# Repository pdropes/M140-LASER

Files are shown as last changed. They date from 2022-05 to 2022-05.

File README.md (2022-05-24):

# 2W LASER - M140 Nichia

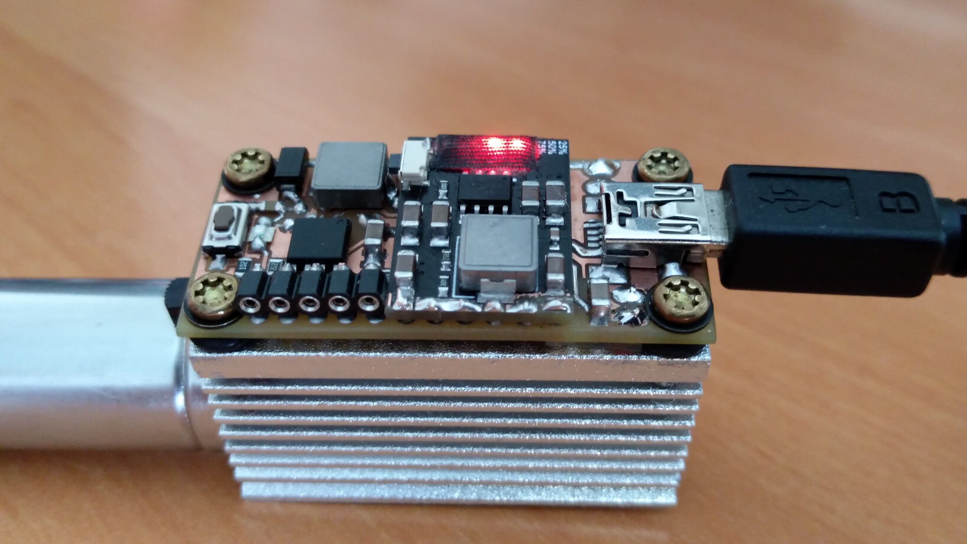
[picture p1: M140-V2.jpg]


Construction of a driver for this small diode, power by 18650 battery.
- Max output = 4.8V 2A
- 4 Selectable power levels (0.1-0.5-1.0-1.5A)
- Constant CC with soft start
- Battery monitoring in charge and discharge

Firmware: Bascom AVR 2.0.8.1; Layout: CadSoft EAGLE 6.5.0

*Stay creative (& always wear safety glasses)

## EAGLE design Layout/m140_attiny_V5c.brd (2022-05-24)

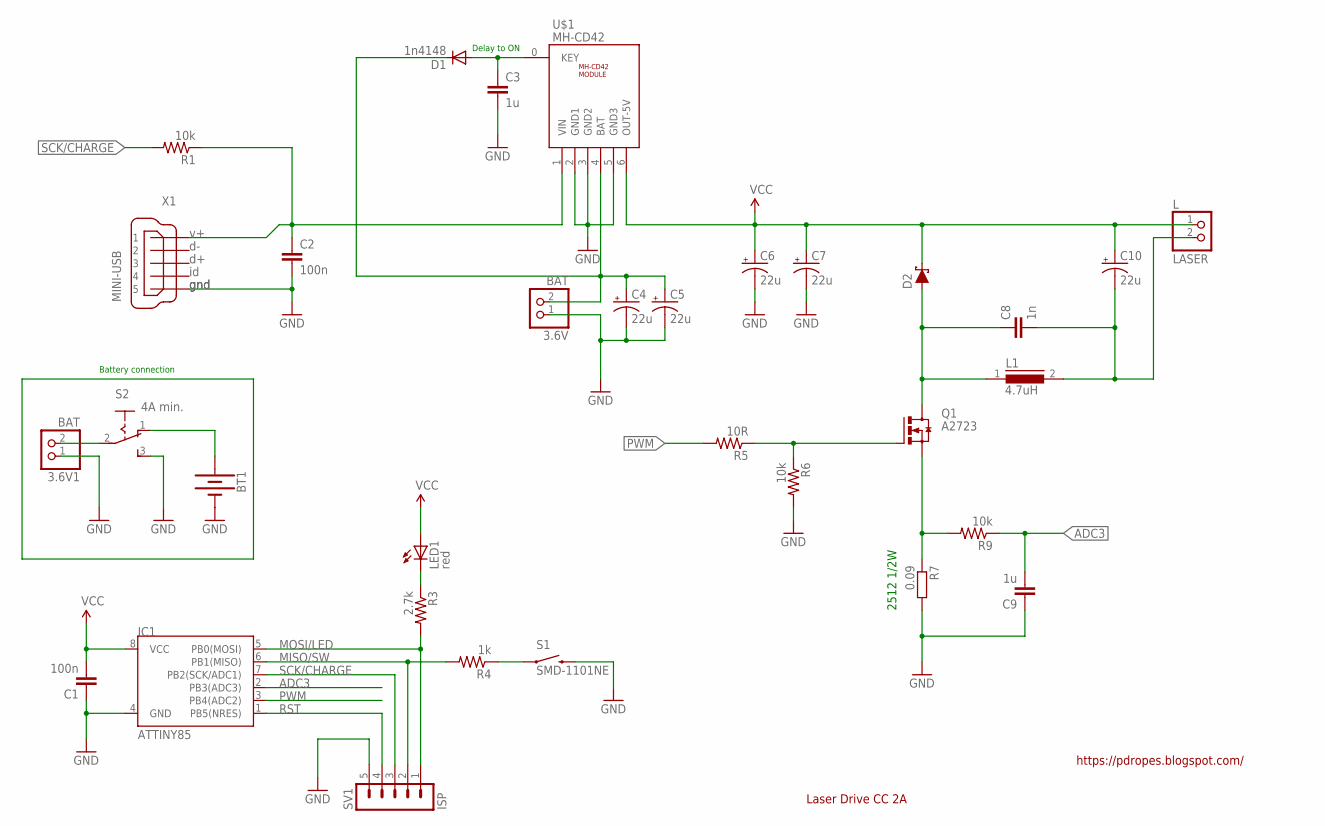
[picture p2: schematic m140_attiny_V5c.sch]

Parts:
3.6V, 3.6V1: BAT; 1X02
BT1: BATTERY-18650; BATTERY_18650-HOLDER
C1, C2: 100n; 0805
C3, C9: 1u; 0805
C4, C5, C6, C7, C10: 22u; EIA3216-KIT
C8: 1n; 0805
D1: 1n4148; MICROMELF-R
D2: 3A/40V/500mV; SMA-DIODE
IC1: ATTINY85; SO08-EIAJ
L: LASER; 1X02
L1: 4.7uH; DR74
LED1: red; CHIPLED_0805
Q1: A2723; SOP-ADVANCE
R1, R6, R9: 10k; 0805
R3: 2.7k; 0805
R4: 1k; 0805
R5: 10R; 0805
R7: 0.09; R2512
S1: SMD-1101NE; TACTILE-SWITCH-1101NE
S2: 4A min.; 255SB
SV1: ISP; MA05-1
U$1: MH-CD42
X1: MINI-USB; 32005-301

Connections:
ADC3: C9.2, IC1.2 (PB3(ADC3)), R9.1
B+: 3.6V.2, C4.A (+), C5.A (+), D1.C, U$1.4 (BAT)
GND: 3.6V.1, 3.6V1.1, BT1.GND@1 (-), C1.1, C2.2, C3.2, C4.C (-), C5.C (-), C6.C (-), C7.C (-), C9.1, IC1.4 (GND), R6.2, R7.2, S1.P$2 (2), S2.3 (S), SV1.5, U$1.2 (GND1), U$1.3 (GND2), U$1.5 (GND3), X1.5
KEY: C3.1, D1.A, U$1.0 (KEY)
L-: C8.2, C10.C (-), L.2, L1.2
MISO/SW: IC1.6 (PB1(MISO)), R4.2, SV1.2
MOSI/LED: IC1.5 (PB0(MOSI)), R3.2, SV1.1
unnamed: BT1.PWR@1 (+), S2.1 (O)
unnamed: R4.1, S1.P$1 (1)
unnamed: 3.6V1.2, S2.2
unnamed: LED1.C, R3.1
PWM: IC1.3 (PB4(ADC2)), R5.2
Q1D: C8.1, D2.A, L1.1, Q1.5 (D), Q1.6 (D), Q1.7 (D), Q1.8 (D), Q1.TH (D)
Q1G: Q1.4 (G), R5.1, R6.1
Q1S: Q1.1 (S), Q1.2 (S), Q1.3 (S), R7.1, R9.2
RST: IC1.1 (PB5(NRES)), SV1.4
SCK/CHARGE: IC1.7 (PB2(SCK/ADC1)), R1.2, SV1.3
USB+: C2.1, R1.1, U$1.1 (VIN), X1.1
VCC: C1.2, C6.A (+), C7.A (+), C10.A (+), D2.C, IC1.8 (VCC), L.1, LED1.A, U$1.6 (OUT-5V)

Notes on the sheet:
Laser Drive CC 2A
gnd
Delay to ON
2512 1/2W
Battery connection
https://pdropes.blogspot.com/

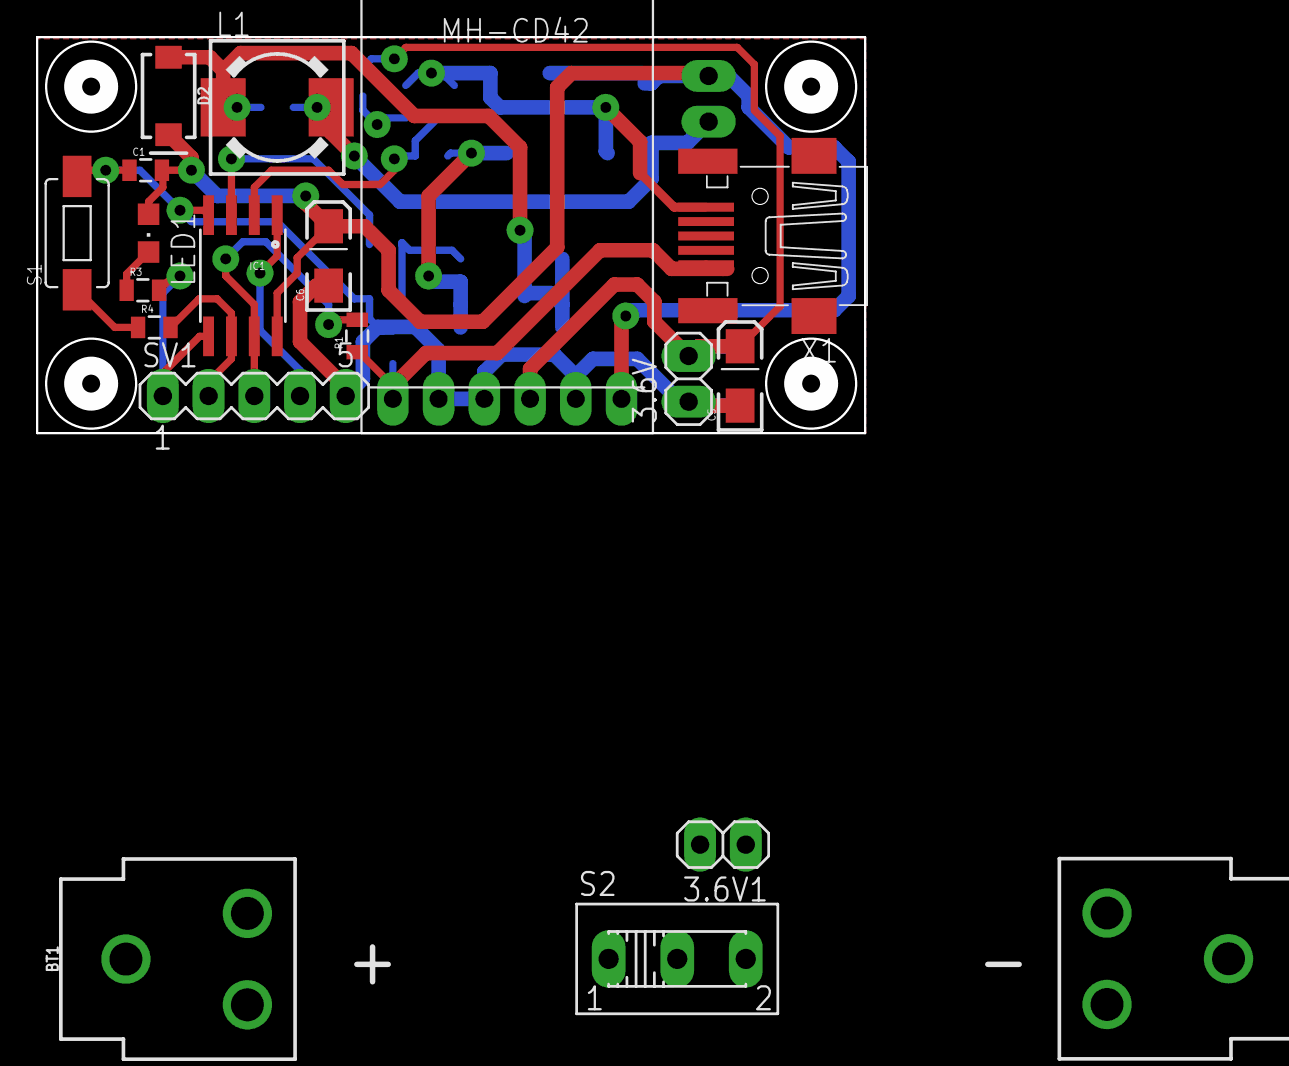
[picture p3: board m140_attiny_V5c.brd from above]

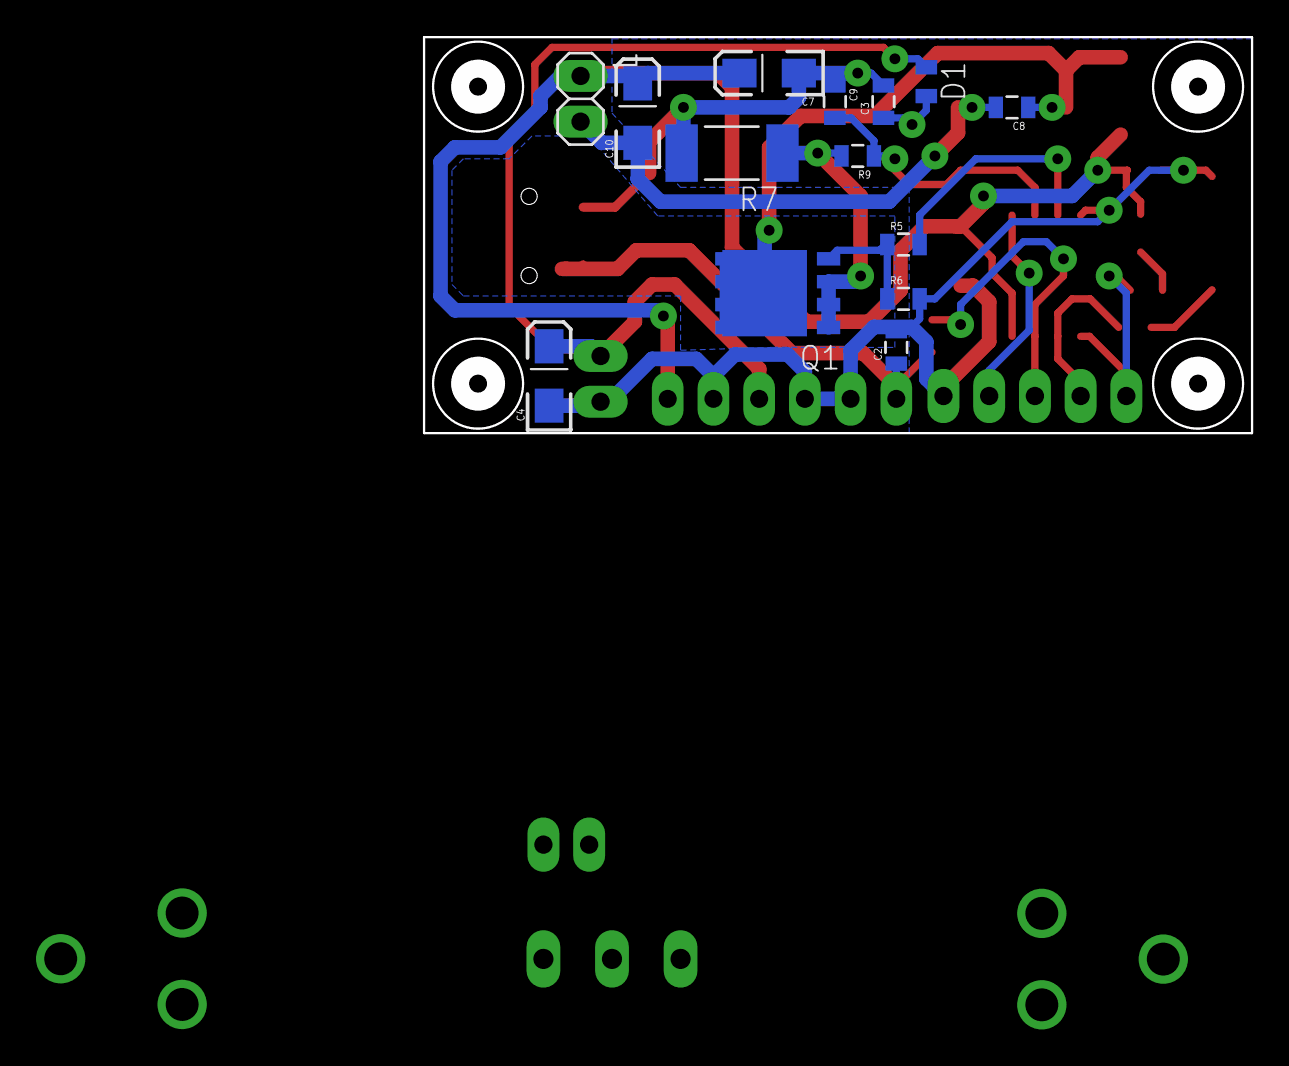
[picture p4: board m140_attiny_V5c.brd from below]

Board: 2 copper layers, 46.0 x 22.0 mm, 33 parts (14 on the bottom side), 19 nets.

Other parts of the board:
U$2: LASER_HEAT_SINK

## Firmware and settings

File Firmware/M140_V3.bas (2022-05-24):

'04-05-2022
'FUSES: E:FF H:DF L:E1

'Pinout ATtiny85:
'1- PB5 (PCINT5 / Reset / ADC0 / DW)
'2- PB3 (PCINT3/XTAL1/CLKI/OC1B/ADC3)
'3- PB4 (PCINT4/XTAL2/CLKO/_OC1B/ADC2)
'4- GND
'5- PB0 (MOSI/DI/SDA/AIN0/OC0A/_OC1A/AREF/PCINT0)
'6- PB1 (MISO/DO/AIN1/OC0B/OC1A/PCINT1)
'7- PB2 (SCK/USCK/SCL/ADC1/T0/INT0/PCINT2)
'8- VCC

'PB0 = SWITCH
'PB1 = LED
'PB2 = USB_charger
'PB3 = ADC3
'PB4 = PWM


$regfile = "attiny85.dat"
$crystal = 16000000
'$hwstack = 32
'$swstack = 10
'$framesize = 40

Dim Value As Word
Dim Ilaser As Word
Dim Cnt , Cnt2 As Word
Dim Pwm_value As Byte

Dim Pselect(4) As Byte                                      'Bascom não aceita arrays de constantes :/

'RSense =0.09ohms
'ADC Ref=1.1V
'Current=1.1V/0.09ohms =12.2(2)A
'LSb=12.2(2)/1024=0.011936V
'0.1A=0.1/ 0.011936V = ~8,4
'0.5A=0.5/ 0.011936V = ~41,9
'1.0A=1.0/ 0.011936V = ~83,8
'1.5A=1.5/ 0.011936V = ~125,7
Pselect(1) = 9 : Pselect(2) = 42 : Pselect(3) = 84 : Pselect(4) = 126       '0.1/0.5/1.0/1.5A


Dim Power_position , Power_output As Word                   'Tem de ser word Power_output

Config Adc = Single , Prescaler = 4 , Reference = Internal_1.1

Const Adc_ilaser = 3

Switch Alias Pinb.0
Led Alias Portb.1
Charger Alias Pinb.2

Config Charger = Input
Charger = 0
Config Led = Output
Led = 1
Config Switch = Input
Switch = 1

Declare Function Get_adc(byval Channel As Byte) As Word
Declare Sub Pwm(_get As Word , _wanted As Word)

'-----------------------------PLL AS CLOCK SOURCE for 16MHz-------------------------
Pllcsr.plle = 1
While Pllcsr.plock = 0
Wend
Pllcsr.pcke = 1
!Ldi R24 , 110
!Out Osccal , R24

'----------------------------TIMER 1 PWM
'TCCR1 – Timer/Counter1 Control Register
'CTC1 PWM1A COM1A1 COM1A0 CS13 CS12 CS11 CS10
Tccr1 = Bits(cs11 , Cs10 )
'GTCCR – General Timer/Counter1 Control Register
'TSM PWM1B COM1B1 COM1B0 FOC1B FOC1A PSR1 PSR0
Gtccr = Bits(pwm1b , Com1b1)
'TCNT1 – Timer/Counter1
Tcnt1 = &H00
Ocr1a = &H00
Ocr1b = &H00                                                'PWM VALUE
Ocr1c = &HFF
Config Portb.4 = Output

'Config Portb.1 = Output
'Open "comb.1:4800,8,n,1" For Output As #1

'------------------------------------------MAIN--------------------------------------------

Enable Interrupts

Power_position = 0
Power_output = Pselect(1)
Pwm_value = 0
Led = 0
Waitms 500
Led = 1

Do
    'Espera que o switch seja activado, pisca a cada segundo
    While Switch = 1

        'Verifica se o carregador está ligado
        While Charger = 1
            Led = 0
            For Cnt = 0 To 100
                If Charger = 0 Then Cnt = 100
                Waitms 5
            Next Cnt
            Led = 1
            For Cnt = 0 To 100
                If Charger = 0 Then Cnt = 100
                Waitms 5
            Next Cnt
        Wend

        For Cnt = 0 To 250
            If Switch = 0 Then Cnt = 250
            Waitms 4
        Next Cnt
        Led = 0
        Waitms 5
        Led = 1
    Wend

    'Se passado 150ms o switch continuar activado, então habilita o laser
    Waitms 150

    Led = 0
    While Switch = 0
        Ilaser = Get_adc(adc_ilaser)
        Call Pwm(ilaser , Power_output)
        Waitms 3                                            'soft start
    Wend
    Led = 1

    'Espera um possível 2º click para alterar a potência
    If Ocr1b = 0 Then
        For Cnt = 0 To 150
            Waitms 1
            If Switch = 0 Then
                Bitwait Switch , Set
                Incr Power_position
                Power_position = Power_position And &B11    '0..3
                Power_output = Pselect(power_position + 1)  'Arrays começam em 1
             'Apresenta a potência
                Waitms 500
                For Cnt2 = 0 To Power_position
                    Led = 0
                    Waitms 100
                    Led = 1
                    Waitms 200
                Next Cnt2
                Cnt = 150
            End If
        Next Cnt
    End If


    Ocr1b = 0                                               'desliga o pwm
    Pwm_value = 0
    Waitms 200
Loop

'---------------------------------------ADC-----------------------------------------------
Function Get_adc(byval Channel As Byte) As Word
    Dim Multi_sample As Byte
    Dim Adc_value As Word

    Adc_value = 0
    For Multi_sample = 0 To 49
        Adc_value = Adc_value + Getadc(channel)
    Next Multi_sample
    Adc_value = Adc_value / 50
    Get_adc = Adc_value
End Function

'-------------------------------------TUNE PWM------------------------------------------
Sub Pwm(_get As Word , _wanted As Word)
    If _get < _wanted And Pwm_value < 200 Then
        Incr Pwm_value
        Ocr1b = Pwm_value
    End If
    If _get > _wanted And Pwm_value > 0 Then
        Decr Pwm_value
        Ocr1b = Pwm_value
    End If
End Sub

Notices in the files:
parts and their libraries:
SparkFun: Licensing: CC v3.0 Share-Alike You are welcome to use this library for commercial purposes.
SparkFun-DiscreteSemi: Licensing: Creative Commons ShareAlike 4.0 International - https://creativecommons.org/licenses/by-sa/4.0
